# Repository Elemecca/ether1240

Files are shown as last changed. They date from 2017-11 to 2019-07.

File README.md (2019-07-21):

# Ethernet Comm Pack for Tektronix 1240

This project is a Comm Pack for the Tektronix 1240 and 1241 logic
analyzers that provides a few interface options:

- [LXI]<sup>&reg;</sup>-compatible<sup><a name="ref1" href="#user-content-note1">1</a></sup> Ethernet
- USB serial (CDC)
- RS-232 serial over DB-9

[LXI]: http://www.lxistandard.org/About/AboutLXI.aspx

## Copyright and License

All files in this repository (with the exception of third-party
documentation under `/docs/datasheets/` and ROM images in `/reverse/`)
are copyright 2017 Sam Hanes.

The documentation under `/docs/` (with the exception of third-party
documentation under `/docs/datasheets/`) is licensed under the
[Creative Commons Attribution-ShareAlike 4.0 International License][CC]
(CC-BY-SA). See `/docs/README.md` for details and `/docs/LICENSE.txt`
for the full license text.

[CC]: https://creativecommons.org/licenses/by-sa/4.0/

The hardware design documentation under `/hardware/` is licensed under
the [CERN Open Hardware Licence][OHL] version 1.2 or newer.
See `/hardware/README.md` for details and `/hardware/LICENSE.txt` for
the full license text.

[OHL]: https://www.ohwr.org/projects/cernohl/wiki/cernohl

<a name="note1" href="#user-content-ref1">Note 1</a>:
LXI<sup>&reg;</sup> is a registered trademark of the LXI Consortium.
This project is not certified by the LXI Consortium. Our use of the
LXI<sup>&reg;</sup> trademark is solely to identify the standard with
which we attempt to comply and should not be taken to imply any
endorsement of this project or its creators by the LXI Consortium.

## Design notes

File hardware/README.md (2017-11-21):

This directory contains the hardware design documentation for the
Ether1240 project. The Schematic and PCB designs are maintained with
the open source [KiCad] EDA package.

[KiCad]: http://kicad-pcb.org/

### Backup ROM Socket

As a backup to the bus controller's ROM emulation, the device has a
15.24mm DIP-28 socket that accepts ROMs compatible with the Intel 27128
EPROM used on the original comm packs. In-circuit programming is
supported for the Atmel AT28C64B and AT28C256 parallel EEPROMs, but only
when the device is disconnected from the 1240 and running on USB power.

## Copyright and License

Copyright 2017 Sam Hanes

This documentation describes Open Hardware and is licensed under the
CERN OHL v1.2.

You may redistribute and modify this documentation under the terms of
the [CERN OHL v.1.2][OHL]. This documentation is distributed WITHOUT ANY
EXPRESS OR IMPLIED WARRANTY, INCLUDING OF MERCHANTABILITY, SATISFACTORY
QUALITY AND FITNESS FOR A PARTICULAR PURPOSE. Please see the CERN OHL
v1.2 for applicable conditions. You should have received a copy of the
OHL alonside this documentation in the file `LICENSE.txt`.

[OHL]: https://www.ohwr.org/projects/cernohl/wiki/cernohl

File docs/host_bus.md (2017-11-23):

The host bus provided to the comm pack on its card-edge connector is in
fact the parallel system bus of the 1240's Z80 IO coprocessor. The comm
pack interface provides for two devices mapped into the Z80's address
space, each with their own select line. A 16KB ROM containing Z80
executable code for the comm pack's communication protocol and
configuration screen is mapped at 0xC000-0xFFFF and selected by the
`/CROM` line. A second, 128-byte region mapped at 0xAE80-0xAEFF and
selected by the `/COMM` line is provided for a type-specific IO device
(e.g. a UART on the RS-232 pack).

## Bus Timing

### Instruction Fetch

instruction fetch timing diagram

No | Parameter                         | Min | Typ | Max | Unit
-- | --------------------------------- | ---:| ---:| ---:| ----
 1 | Address valid to `/CROM` fall     |  16 |     | 259 | ns
 2 | Address valid to `/RD` fall       |
 3 | `/RD` fall to `/RD` rise          |
 4 | Data setup time to `/RD` rise     |
 5 | Data hold time after `/RD` rise   |

It's important to note that the order in which `/CROM` and `/RD` fall is
undefined and may vary.

<!--
  1 Minimum (Address valid to /CROM fall)
    + 65 ns  min. Z80 address valid to /MREQ fall
    + 0  ns  min. decode delay, /MREQ fall to /CROM fall
    - 49 ns  max. buffer delay, Z80 to IA[0..13]
    = 16 ns

  1 Typical (Address valid to /CROM fall)
    + ??
    + 29 ns  typ. decode delay, /MREQ fall to /CROM fall
    - 27 ns  typ. buffer delay, Z80 to IA[0..13]
    = ???

  1 Maximum (Address valid to /CROM fall)
    -   0 ns  min. Z80 address valid from T1 rise
    + 125 ns  half clock cycle (rise to fall)
    +  85 ns  max. Z80 T1 fall to /MREQ fall
    +  49 ns  max. decode delay, /MREQ fall to /CROM fall
    -   0 ns  min. buffer delay, Z80 to IA[0..13]
    = 259 ns

  Empirical measurements (at 2V threshold):
    /MREQ fall to /CROM fall  47 ns
    /MREQ fall to /RD   fall   8 ns
    /RD   fall to /IRD  fall  31 ns
    /IRD  fall to /CROM fall  10ns
 -->

## Bus Structure

The Z80 is clocked at 4MHz. Tektronix have added a wait circuit that
asserts the `/WAIT` line for one clock cycle during the M1 machine cycle
in order to allow extra time for IO devices to respond.

### Address Lines

The Z80 has a 16-bit address bus, of which several lines are decoded.
The address bus is bufferred immediately after leaving the Z80 yielding
the `BA[0..15]` bus, which is internal to the IO Processor card. Lines
0..11 use a pair of Motorola 74LS244 buffers with their enable lines
tied, giving a delay of 0-18ns (12ns typical). Lines 12..15 use a
Motorola 74LS75 D latch with its (active high) enable inputs driven by
the `/MREQ` line, giving a delay of 0-27ns (15ns typical) on input or
enable.

All but the high-order two lines of the `BA[0..15]` bus are then
buffered again to produce the `IA[0..13]` bus, which is exported via the
backplane connector to other cards and the comm pack. Lines 0..5 use a
Motorola 74LS365 buffer with its enable lines tied, giving a delay of
0-22ns (10ns typical). Lines 6..13 use a Motorola 74LS244 buffer with
its enable lines tied, giving a delay of 0-18ns (12ns typical).

The `IA[0..13]` bus as a whole therefore stabilizes 0-49ns (27ns
typical) after the processor outputs if `/MREQ` is already inactive, or
after the inactive-going edge on `/MREQ` otherwise.

### Select Lines

The device select lines are decoded from the `BA[0..15]` bus. Two lines
are of interest to us -- `/CROM` and `/COMM` -- and they're decoded via
very different paths. All of the decode circuits use the `/BMREQ` line,
which is buffered from the `/MREQ` line via a Motorola 74LS244 with its
enable lines tied, giving a delay of 0-18ns (12ns typical).

The `/CROM` line is decoded from `BA[13..15]` via a TI 74S138, giving a
delay of 0-11ns (7ns typical) on enable. The outputs corresponding to
input of 110 and 111 are logical-ORed to form the `/CROM` line via a TI
74LS08, giving a delay of 0-20ns (10ns typical). The decoder's (active
low) enable inputs are driven by the `/BMREQ` line, so the total delay
is 0-49ns (29ns typical) from the falling edge of `/MREQ`. The buffer
delay for `BA[13..15]` is irrelevant as the time at the Z80 from address
valid to `/MREQ` fall is always more than the buffer delay.
<!-- measured 30ns at 10ns resolution, so typical is bang on -->

The `/COMM` line is decoded from `BA[7..15]` through several steps.
First, the enable signal for a TI 74S139 (which has a maximum delay of
12ns on either enable or decode) is driven by the output corresponding
to 101 of the same 74S138 as in the `/CROM` chain. The 74S139 decodes
the `/LATCHES` signal from `BA[11..12]` when its input is 10. The
`/COMM` signal is then decoded from `BA[7..10]` on an input of 1011
by another TI 74LS138 with its (active low) enable inputs driven by
`/LATCHES`, giving a maximum delay of 12ns on enable or input. The total
delay is therefore 56ns from the falling edge of `/MREQ`.

### Enable Lines

### Data Lines

The Z80 has an 8-bit bidirectional tri-state data bus. The data lines at
the processor form the `DD[0..7]` bus, which is internal to the IO
Processor card. For output, the `DD[0..7]` bus is latched through a
Motorola 74LS373 to form the `ID[0..7]` bus, which is exported via the
backplane connector to other cards and the comm pack. The latch outputs
go high-impedance when the `/IRD` line is asserted, but otherwise it
drives the bus all the time. The latch has a maximum propagation delay
of 18ns. Its maximum enable delay is 36ns, but that shouldn't matter.

For input, the `ID[0..7]` bus is buffered on to the `DD[0..7]` bus via a
NatSemi 81LS95 buffer, giving a maximum delay of 40ns. Its maximum
enable delay is 42ns and its maximum disable delay is 27ns, but those
shouldn't matter.

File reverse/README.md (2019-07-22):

# Reverse Engineering Files

This directory contains the working files for reverse engineering the
interface between the comm pack and the IO processor.

- `tek1241.*` is a Ghidra project for reverse engineering the ROMs

- `chargen.py` generates an SVG map of the 1240's proprietary character
  set from the character generation ROM image

## ROM Files

| Part Number | Designator | Address | Description
| --- | --- | --- | ---
| 160-1915-00 | A31 U126 | C000-FFFF | RS-232 Comm Pack (B010100-B019999)
| 160-1915-01 | A31 U126 | C000-FFFF | RS-232 Comm Pack (B012000-present)
| 160-1916-01 | A32 U245 | C000-FFFF | GPIB Comm Pack
| 160-3072-00 | A10 U160 | 0000-1FFF | IO Processor 1
| 160-3073-00 | A10 U165 | 2000-3FFF | IO Processor 2
| 160-3074-00 | A10 U170 | 4000-5FFF | IO Processor 3
| 160-3075-00 | A10 U180 | 6000-7FFF | IO Processor 4
| 160-3076-00 | A10 U185 | 8000-9FFF | IO Processor 5
| 160-3077-00 | A12 U175 | E000-FFFF | Display (1241 only)
| 160-3078-00 | A12 U130 | N/A | Character Gen

Only one of 160-1915-xx and 160-1916-xx will be present at once as they
belong to different comm packs.

The comm pack ROM 160-191x-xx and the display board ROM 160-3077-xx are
bank switched in the 1241 and occupy the same address space. If bit 3
at AC00 (A12 U420) is low the display ROM is selected. If it's high
the comm pack ROM is selected.

## Copyright and License

The ROM images (`.bin` files) are copyright Tektronix.

Other files in this directory were written by Sam Hanes in 2017.
To the extent possible under law, the author(s) have dedicated all
copyright and related and neighboring rights to this software to the
public domain worldwide. This software is distributed without any
warranty.

You should have received a copy of the CC0 Public Domain Dedication
along with this software. If not, see
  http://creativecommons.org/publicdomain/zero/1.0/

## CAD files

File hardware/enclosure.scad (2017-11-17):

/* Copyright 2017 Sam Hanes
 *
 * This documentation describes Open Hardware and is licensed under the
 * CERN Open Hardware License v1.2.
 *
 * You may redistribute and modify this documentation under the terms of
 * the CERN OHL v.1.2O. This documentation is distributed WITHOUT ANY
 * EXPRESS OR IMPLIED WARRANTY, INCLUDING OF MERCHANTABILITY, SATISFACTORY
 * QUALITY AND FITNESS FOR A PARTICULAR PURPOSE. Please see the CERN OHL
 * v1.2 for applicable conditions. You should have received a copy of the
 * OHL alonside this documentation in the file `LICENSE.txt`.
 */


module box(size, slope) {
  x = size[0] / 2;
  y = size[1] / 2;
  z = size[2];
  i = slope * z;

  polyhedron(
    points = [
      [-x + i, -y + i, 0], // 0
      [ x - i, -y + i, 0], // 1
      [ x - i,  y - i, 0], // 2
      [-x + i,  y - i, 0], // 3
      [-x,     -y,     z], // 4
      [ x,     -y,     z], // 5
      [ x,      y,     z], // 6
      [-x,      y,     z], // 7
    ],
    faces = [
      [0, 1, 2, 3],
      [4, 5, 1, 0],
      [7, 6, 5, 4],
      [5, 6, 2, 1],
      [6, 7, 3, 2],
      [7, 4, 0, 3],
    ]
  );
}

sizeX = 2.610;
sizeY = 4.060;
sizeZ = 0.740;

sizeX2 = 2.560;
thick = 0.055;

slope = (sizeX - sizeX2) / sizeZ;

difference() {
  box([sizeX, sizeY, sizeZ], slope);

  t2 = thick * 2;
  translate([0, 0, thick])
    box([sizeX - t2, sizeY - t2, sizeZ], slope);
}

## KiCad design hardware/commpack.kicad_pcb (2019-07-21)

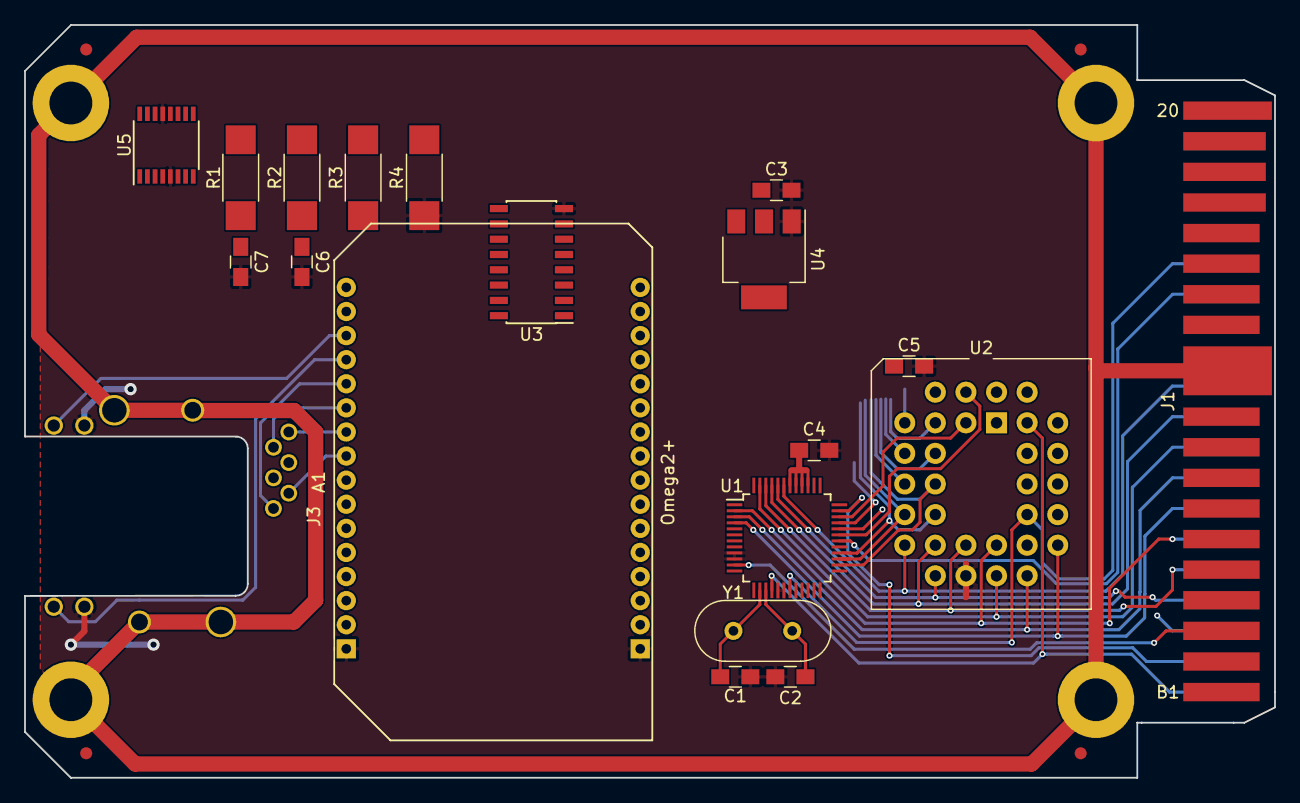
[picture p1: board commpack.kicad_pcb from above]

Board: 2 copper layers, 103.8 x 62.5 mm, 29 parts (0 on the bottom side), 57 nets.

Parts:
A1: Omega2+; Omega2
Bonsai: Bonsai
C1, C2, C3, C4, C5: 22u; C_0805_HandSoldering
C6, C7: 47p; C_0805_HandSoldering
FD1, FD2, FD3, FD4: Fiducial_1mm_Dia_2mm_Outer
H1, H2, H3, H4: Mount; MountingHole_140mil_Pad
J1: 1240COMM
J3: L8BE-1G1T-91A
R1, R2: 27R; R_2010_HandSoldering
R3: 4k7; R_2010_HandSoldering
R4: 10k; R_2010_HandSoldering
U1: SC16C550B; LQFP-48_7x7mm_Pitch0.5mm
U2: SST39SF010A; PLCC-32_THT-Socket
U3: HCF4010; SOIC-16_3.9x9.9mm_Pitch1.27mm
U4: AP1117-33; SOT-223-3_TabPin2
U5: FT230XS; SSOP-16_3.9x4.9mm_Pitch0.635mm
Y1: 22.1184M; Crystal_HC49-U_Vertical

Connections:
+3V3: A1.B2, C3.1, U3.1, U4.2, U5.3, U5.10, U5.11, U5.12
/A-RX: A1.A8, U3.4
/A-TX: A1.A9, U1.7
/A-~CTS: A1.A7, U3.2
/A-~RTS: A1.A6, U1.38
/E-LED1: A1.B13, J3.14
/E-LED2: A1.B14, J3.16
/E-RX+: A1.B12, J3.4
/E-RX-: A1.B11, J3.6
/E-TX+: A1.B10, J3.12
/E-TX-: A1.B9, J3.10
/H-A0: J1.A16, U1.28, U2.12
/H-A1: J1.B1, U1.27, U2.11
/H-A2: J1.A17, U1.26, U2.10
/H-A3: J1.B2, U2.9
/H-A4: J1.A18, U2.8
/H-A5: J1.A3, U2.7
/H-A6: J1.B16, U2.6
/H-A7: J1.B4, U2.5
/H-A8: J1.B15, U2.27
/H-A9: J1.B5, U2.26
/H-A10: J1.B14, U2.23
/H-A11: J1.B6, U2.25
/H-A12: J1.B13, U2.4
/H-A13: J1.B7, U2.28
/H-D0: J1.A11, U1.43, U2.13
/H-D1: J1.A4, U1.44, U2.14
/H-D2: J1.A10, U1.45, U2.15
/H-D3: J1.A5, U1.46, U2.17
/H-D4: J1.A9, U1.47, U2.18
/H-D5: J1.A6, U1.2, U2.19
/H-D6: J1.A8, U1.3, U2.20
/H-D7: J1.A7, U1.4, U2.21
/H-INT: J1.A14, U1.30
/H-RST: J1.A2, U1.35
/H-~CS: J1.B3, U1.11
/H-~RD: J1.A15, U1.19, U2.24
/H-~RS: J1.A13, U2.22
/H-~WR: J1.A1, U1.16, U2.31
/R-A14: U1.33, U2.29
/R-A15: U1.34, U2.3
/R-A16: U1.31, U2.2
/U-TX: U1.8, U3.5
/U-~RTS: U1.32, U3.3
Earth_Protective: H1.1, H2.1, H3.1, H4.1, J1.B11, J3.17, J3.18, J3.19, J3.20
GND: A1.A1, A1.B1, C1.2, C2.2, C3.2, C4.2, C5.2, C6.2, C7.2, J1.A20, J1.B20, J3.13, J3.15, R4.2, U1.9, U1.10, U1.17, U1.18, U1.20, U1.24, U2.16, U3.8, U4.1, U5.5, U5.13
unnamed: A1.B5, U5.1
unnamed: A1.B6, U5.4
unnamed: C1.1, U1.14, Y1.1
unnamed: C2.1, U1.15, Y1.2
unnamed: C6.1, R2.1
unnamed: C7.1, R1.1
unnamed: R1.2, U5.9
unnamed: R2.2, U5.8
unnamed: R3.2, R4.1, U5.15
unnamed: U1.5, U1.12
VCC: C4.1, C5.1, J1.A19, J1.B19, U1.39, U1.40, U1.41, U1.42, U2.32, U3.16, U4.3

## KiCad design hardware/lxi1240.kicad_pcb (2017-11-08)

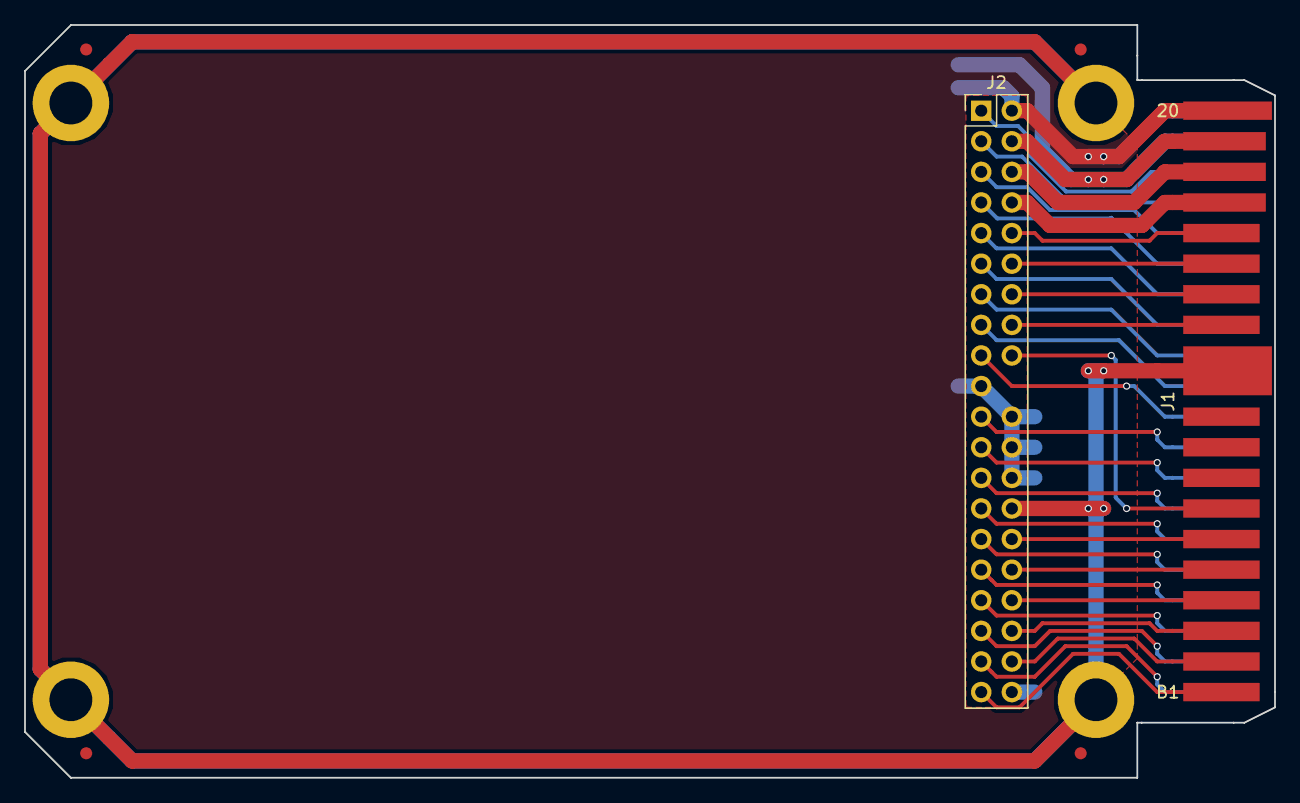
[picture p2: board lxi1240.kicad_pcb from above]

Board: 2 copper layers, 103.8 x 62.5 mm, 11 parts (0 on the bottom side), 34 nets.

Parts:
Bonsai: Bonsai
FD1, FD2, FD3, FD4: Fiducial_1mm_Dia_2mm_Outer
H1, H2, H3, H4: Mount; MountingHole_140mil_Pad
J1: 1240COMM
J2: 1240COMM_EXT; ATA_HEADER

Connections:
+5V: J1.A19, J1.B19, J2.4
+12VA: J1.B17, J2.8
-12VA: J1.B18, J2.6
/H-A0: J1.A16, J2.5
/H-A1: J1.B1, J2.39
/H-A2: J1.A17, J2.3
/H-A3: J1.B2, J2.38
/H-A4: J1.A18, J2.1
/H-A5: J1.A3, J2.33
/H-A6: J1.B16, J2.10
/H-A7: J1.B4, J2.34
/H-A8: J1.B15, J2.12
/H-A9: J1.B5, J2.32
/H-A10: J1.B14, J2.14
/H-A11: J1.B6, J2.30
/H-A12: J1.B13, J2.16
/H-A13: J1.B7, J2.18
/H-D0: J1.A11, J2.15
/H-D1: J1.A4, J2.31
/H-D2: J1.A10, J2.17
/H-D3: J1.A5, J2.29
/H-D4: J1.A9, J2.21
/H-D5: J1.A6, J2.27
/H-D6: J1.A8, J2.23
/H-D7: J1.A7, J2.25
/H-INT: J1.A14, J2.9
/H-RST: J1.A2, J2.35
/~H-CS: J1.B3, J2.36
/~H-RD: J1.A15, J2.7
/~H-RS: J1.A13, J2.11
/~H-WR: J1.A1, J2.37
Earth_Protective: H1.1, H2.1, H3.1, H4.1, J1.B11, J2.28
GND: J1.A20, J1.B20, J2.2, J2.19, J2.22, J2.24, J2.26, J2.40
unnamed: J1.A12, J2.13

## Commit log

2017-11-04 Set up basic board outline and card edge connector.
    [lxi1240.kicad_pcb, lxi1240.sch]
2017-11-05 Make board-edge symbol compliant with KLC.
    [lxi1240.sch]
2017-11-05 Add a breakout header for the board edge connector.
    [lxi1240.kicad_pcb, lxi1240.sch]
2017-11-05 Add mounting holes with protective ground.
    [lxi1240.kicad_pcb, lxi1240.sch]
2017-11-05 Add ground pours.
    [lxi1240.kicad_pcb]
2017-11-05 Remove pad for key pin in ATA header.
    [lxi1240.kicad_pcb, lxi1240.sch]
2017-11-05 Move PE to ATA pin 28 so slave connector is usable.
    [lxi1240.kicad_pcb]
2017-11-05 Shorten ground paths.
    [lxi1240.kicad_pcb]
2017-11-05 Add fiducials and chamfer corners.
    [lxi1240.kicad_pcb]
2017-11-05 Add CERN OHL license notices.
    [lxi1240.kicad_pcb, lxi1240.sch]
2017-11-08 Update board for more accurate measurements of the original.
    [lxi1240.kicad_pcb, lxi1240.sch]
2017-11-08 Move ATA header closer to board edge.
    [lxi1240.kicad_pcb]
2017-11-08 Add a PIC micro to manage the host bus.
    [lxi1240.sch]
2017-11-17 Start building enclosure in OpenSCAD.
    [enclosure.scad]
2017-11-17 enclosure: center box and use slope instead of inset.
    [enclosure.scad]
2017-11-21 Rename project files to remove LXI mark.
    [commpack.kicad_pcb, commpack.sch]
2017-11-21 Build footprint for MagJack.
    [commpack.kicad_pcb]
2017-11-21 Remove PIC16, add Ethernet port to schematic, fix SGND.
    The PIC16 micro isn't fast enough to perform reliable bus emulation.
    [commpack.kicad_pcb, commpack.sch]
2017-11-21 Add USB-B connector.
    [commpack.kicad_pcb, commpack.sch]
2017-11-21 Add ground pour over card-edge connector.
    [commpack.kicad_pcb]
2017-11-21 Add 27128 socket to PCB and route it.
    [commpack.kicad_pcb]
2017-11-22 Make routing for ROM socket more compact.
    [commpack.kicad_pcb]
2017-11-23 Duplicate trace cleanup on export.
    [commpack.kicad_pcb]
2017-11-30 Add Omega2 footprint to board.
    [commpack.kicad_pcb, commpack.sch]
2017-11-30 Reroute traces under 27C128 socket again.
    [commpack.kicad_pcb]
2017-12-03 Change ATA pinout, rip up EPROM socket and Omega2.
    I missed two grounded pins when I did the original ATA connector pinout,
    so this drops the +12V and -12V connections and rearranges everything to
    avoid shorting two of the address lines to ground.
    [commpack.kicad_pcb, commpack.sch]
2017-12-04 Clean up routing from card edge to ATA connector.
    [commpack.kicad_pcb]
2019-07-21 Add UART, flash ROM to schematic.
    [commpack.sch]
2019-07-21 Place UART and ROM, route data bus.
    [commpack.kicad_pcb]
2019-07-21 Route the remaining signals.
    [commpack.kicad_pcb]
2019-07-21 Fix up rear silkscreen.
    [commpack.kicad_pcb]
2019-07-21 Add decoupling caps on UART and ROM.
    [commpack.kicad_pcb, commpack.sch]
2019-07-21 Fix via size on power traces.
    [commpack.kicad_pcb]
2019-07-21 Reduce mask expansion to get fingers between UART pads.
    [commpack.kicad_pcb]
2019-07-21 Add a level shifter on the serial lines to the Omega2.
    [commpack.kicad_pcb, commpack.sch]
2019-07-21 Switch Y1 to through-hole footprint.
    [commpack.sch]
2019-07-21 Fix alignment of crystal traces.
    [commpack.kicad_pcb]
2019-07-21 Clean up ground planes a bit.
    [commpack.kicad_pcb]
2019-07-21 Clean up track with and spacing.
    [commpack.kicad_pcb]
2019-07-21 Update schematic to KiCAD 5.0.
    [commpack.sch]
2019-07-21 Some WIP on the UART board.
    I don't actually know what changed; this was months ago.
    [commpack.kicad_pcb, commpack.sch]
2019-07-21 Rename local libraries.
    [commpack.kicad_pcb, commpack.sch]

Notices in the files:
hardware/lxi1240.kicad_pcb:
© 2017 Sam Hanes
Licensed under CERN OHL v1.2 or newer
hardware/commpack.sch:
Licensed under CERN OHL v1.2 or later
